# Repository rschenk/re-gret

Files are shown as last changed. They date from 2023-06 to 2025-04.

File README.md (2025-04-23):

# Re-gret Keyboard

The Re-gret is a 34 key remix of my [Egret](https://github.com/rschenk/egret) keyboard.

Featuring: 34 keys, Choc spacing, Choc v1 hot swappable, Seeed Xiao MCU, wireless compatible, RGB undeglow when plugged in, and a silicone gasket sandwich stackup.

Compared to the original Egret, besides having two thumb buttons per side, the Re-gret has a more angle between the halves, and the ring and pinky fingers have more stagger and more splay. It also has a Xiao MCU which is cheaper and cuter than a Nice Nano. Certainly a more re-fined re-mix that I have no re-grets about making.

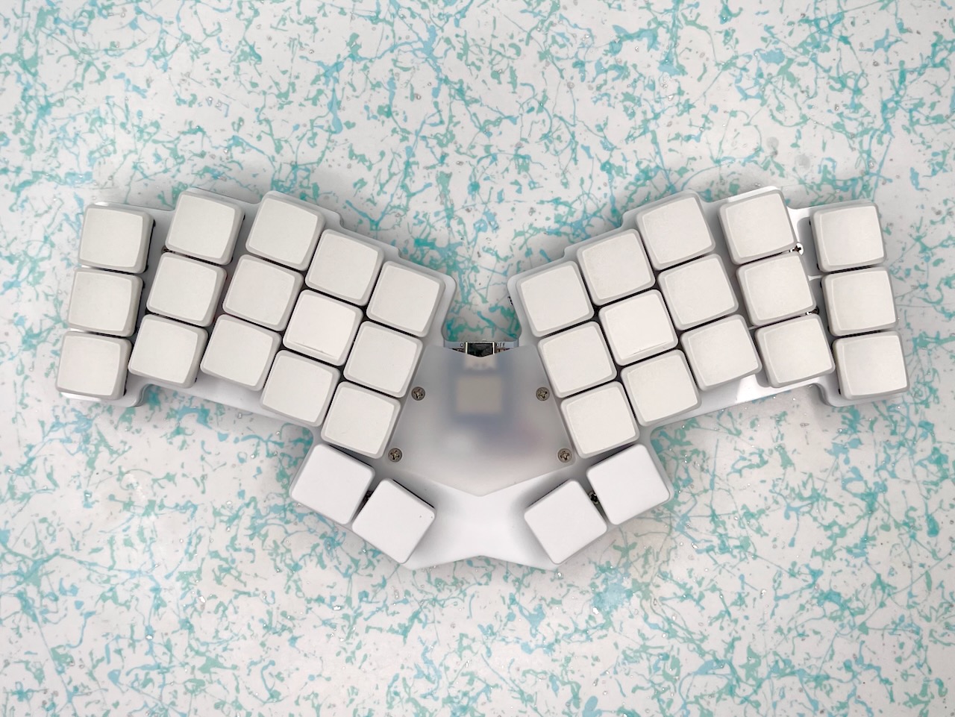
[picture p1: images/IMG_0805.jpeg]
Re-gret Bluetooth Mode


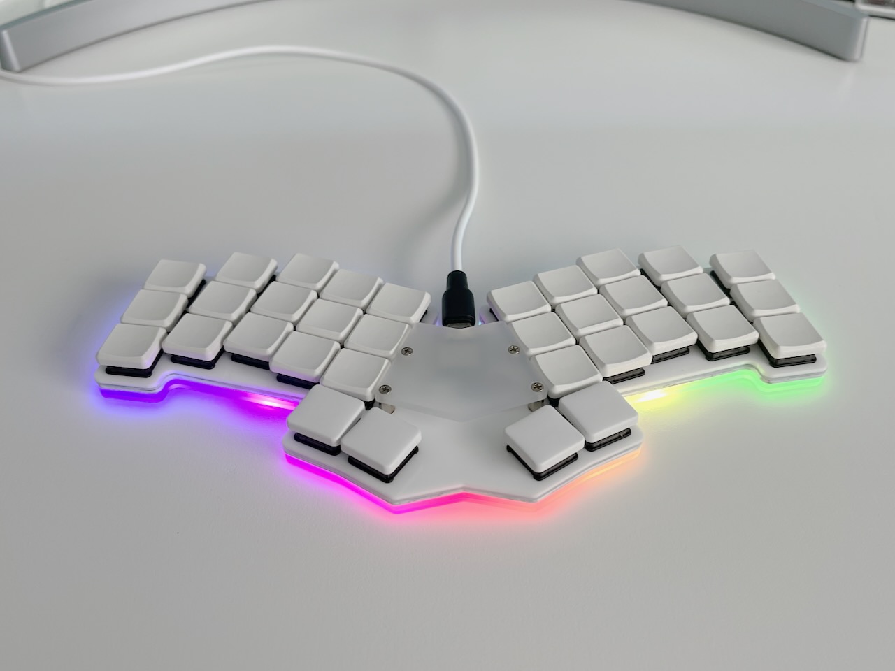
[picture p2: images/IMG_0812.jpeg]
Re-gret Underglow


## Build guide

Check the docs for a [PCB Build Guide](docs/pcb_build_guide.md) and [Case Build Guide](docs/case_build_guide.md).

## RGB Underglow

I powered the RGB underglow directly from the USB 5v, so it will automagically turn itself off when in wireless bluetooth mode. There's no need for ZMK's [External Power Control](https://zmk.dev/docs/behaviors/power#external-power-control) because you physically can't run the LEDs from battery power even if you wanted to. There's a [clever trick](https://hackaday.com/2017/01/20/cheating-at-5v-ws2812-control-to-use-a-3-3v-data-line/) using a diode that allows the 5v LEDs to be controlled by the Xiao's 3.3v logic.

## Firmware

### ZMK

I've published the firmware for Re-gret as a ZMK module: [rschenk/zmk-keyboard-re-gret](https://github.com/rschenk/zmk-keyboard-re-gret), which is (probably?) the preferred method for adding the keyboard in ZMK.

If you don't use modules, or prefer the old school way, then copy the contents of `firmware/zmk/config/boards/shields/regret/` into `[your-zmk-config]/config/boards/shields/regret/`

Be advised that right now the underglow only works on the XIAO nRF52840 board, and does not work on the XIAO RP2040 (although it [might in the future](https://github.com/zmkfirmware/zmk/issues/1085)). The original XIAO SAMD21 should work but I haven't tested it.

| Board | Chip | USB Wired | Bluetooth Wireless | RGB Underglow | Comments |
| --- | --- | --- | --- | --- | --- |
| XIAO | SAMD21 | :white_check_mark: | :x: | :x: | Should work but untested |
| XIAO BLE | nRF52840 | :white_check_mark: | :white_check_mark: | :white_check_mark: | |
| XIAO RP2040 | RP2040 | :white_check_mark: | :x: | :x: for now | Underglow [maybe someday](https://github.com/zmkfirmware/zmk/issues/1085) |

### QMK

Copy the contents of `firmware/qmk/keyboards/re_gret` into `[your_qmk_firmware]/keyboards/re_gret`, since I have not put the Re-gret firmware into the official QMK repo.

Only the XIAO RP2040 is supported. The Adafruit QT Py RP2040 might possibly work but I don't think the reset button will function.

| Board | Chip | USB Wired | RGB Underglow | Comments |
| --- | --- | --- | --- | --- |
| XIAO RP2040 | RP2040 | :white_check_mark: | :white_check_mark: |  |

## Related

* I cribbed the Xiao footprint, pogo pin idea, and battery from the [revxlp](https://gitlab.com/lpgalaxy/revxlp)
* I based the QMK shift register matrix code on [Sadek's](https://github.com/sadekbaroudi/qmk_firmware)
* My original 36 key [Egret](https://github.com/rschenk/egret) was the starting point

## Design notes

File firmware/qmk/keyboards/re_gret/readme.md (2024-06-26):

# Re-gret

re_gret

A 34-key keyboard powered by a Seeed XIAO RP2040, with hot-swappable ChocV1 switches.

* Keyboard Maintainer: [Ryan Schenk](https://github.com/rschenk)
* Hardware Supported: Re-gret PCB with Seeed XIAO RP2040 controller
* Hardware Availability: Gerbers are available in the [Re-gret repo](https://github.com/rschenk/re-gret) and the controller is available from [Seeed Studio](https://www.seeedstudio.com/XIAO-RP2040-v1-0-p-5026.html)

Make example for this keyboard (after setting up your build environment):

    make re_gret:default

Flashing example for this keyboard:

    make re_gret:default:flash

See the [build environment setup](https://docs.qmk.fm/#/getting_started_build_tools) and the [make instructions](https://docs.qmk.fm/#/getting_started_make_guide) for more information. Brand new to QMK? Start with our [Complete Newbs Guide](https://docs.qmk.fm/#/newbs).

## Bootloader

Enter the bootloader in 3 ways:

* **Bootmagic reset**: Hold down the top-left key ("Q" on qwerty) and plug in the keyboard
* **Physical reset button**: Double click the reset button
* **Keycode in layout**: Press the key mapped to `QK_BOOT` if it is available

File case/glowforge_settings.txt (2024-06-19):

Laser cutting settings for Glowforge Pro

1/16" Acrylic:
Speed: 241
Power: Full

To engrave the footpad wells:
Speed: 544
Power: 60
LPI: 270

Silicone Gasket:
Speed: 204
Power: 75

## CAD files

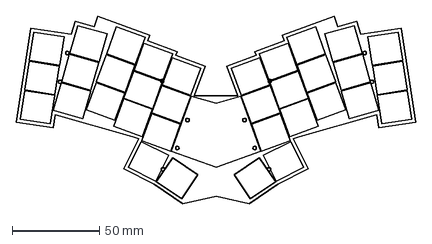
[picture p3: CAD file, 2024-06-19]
ergogen/output/outlines/comp.dxf
229.0 x 107.1 mm

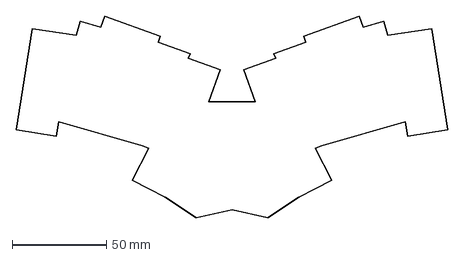
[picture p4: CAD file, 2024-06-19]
ergogen/output/outlines/board.dxf
229.0 x 107.1 mm

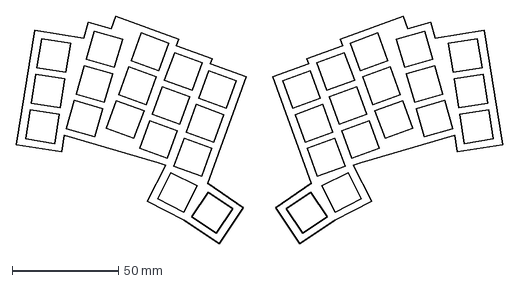
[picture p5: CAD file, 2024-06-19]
ergogen/output/outlines/top_plate.dxf
229.0 x 107.1 mm

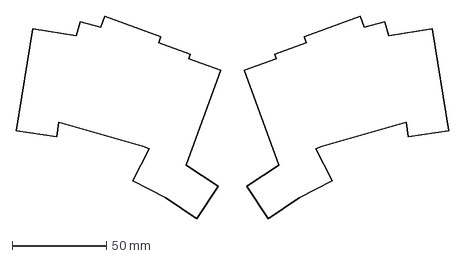
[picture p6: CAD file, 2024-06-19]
ergogen/output/outlines/raw.dxf
229.0 x 107.1 mm

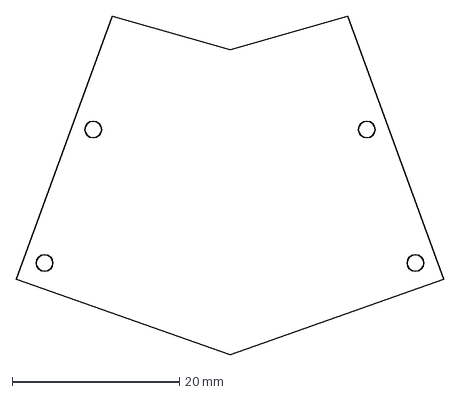
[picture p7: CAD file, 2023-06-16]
ergogen/output/outlines/mcu_cover.dxf
51.1 x 40.5 mm

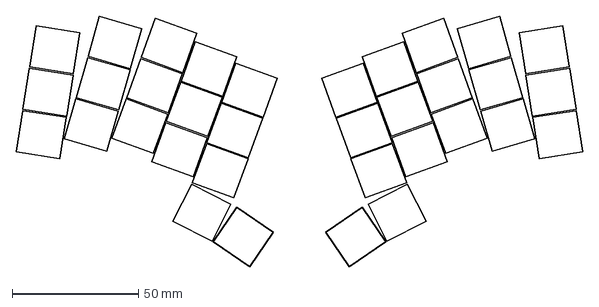
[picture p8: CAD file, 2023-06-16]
ergogen/output/outlines/keycaps.dxf
224.4 x 99.1 mm

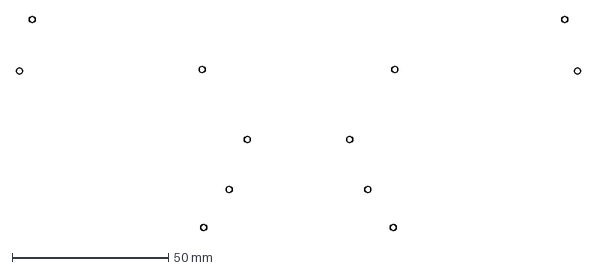
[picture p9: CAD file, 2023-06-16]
ergogen/output/outlines/all_mounting_holes.dxf
180.5 x 68.6 mm

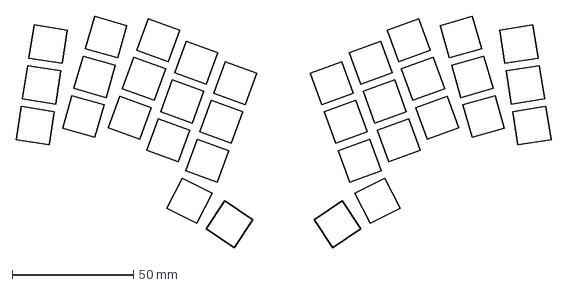
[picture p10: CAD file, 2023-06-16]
ergogen/output/outlines/switch_holes.dxf
220.4 x 95.3 mm

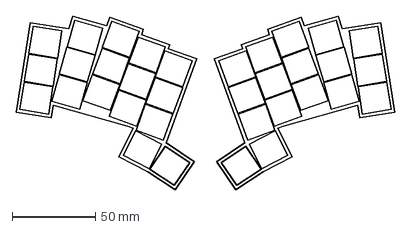
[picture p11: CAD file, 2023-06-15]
ergogen/output/outlines/keys.dxf
227.4 x 104.4 mm

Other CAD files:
case/dxf/Regret_Bottom_Plate_Outer.dxf
case/dxf/Regret_Bottom_Gasket.dxf
case/dxf/Regret_Bottom_Plate_Inner.dxf
case/dxf/Regret_Top_Plate.dxf
case/dxf/Regret_Top_Gasket.dxf
case/dxf/Regret_MCU_Cover.dxf

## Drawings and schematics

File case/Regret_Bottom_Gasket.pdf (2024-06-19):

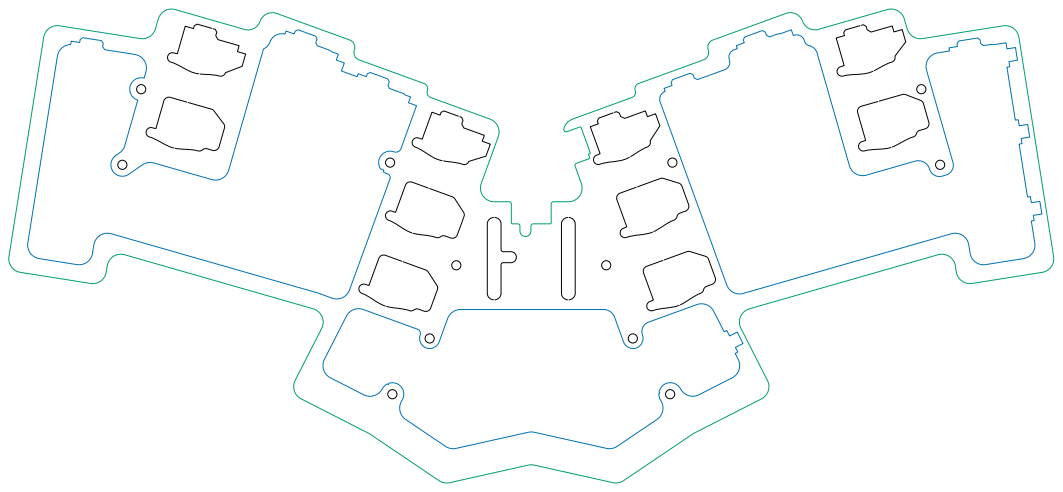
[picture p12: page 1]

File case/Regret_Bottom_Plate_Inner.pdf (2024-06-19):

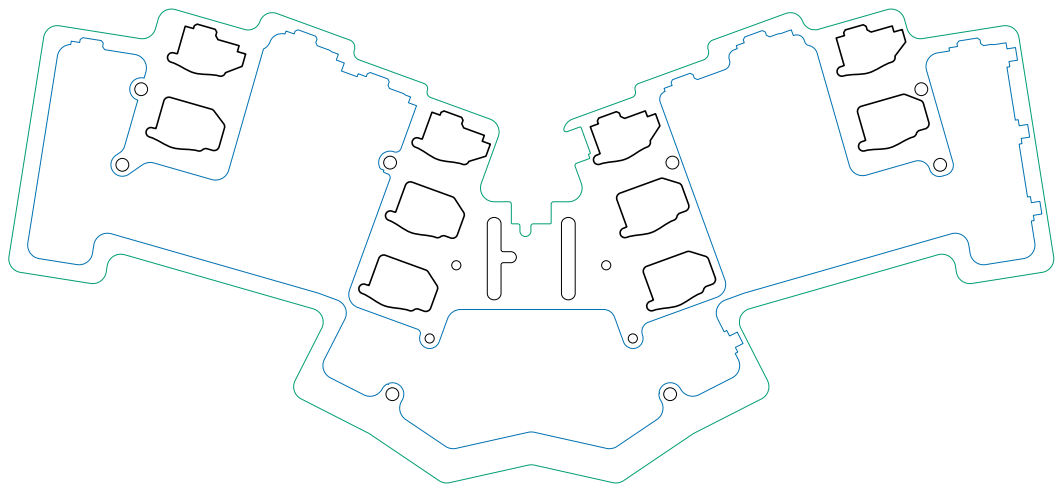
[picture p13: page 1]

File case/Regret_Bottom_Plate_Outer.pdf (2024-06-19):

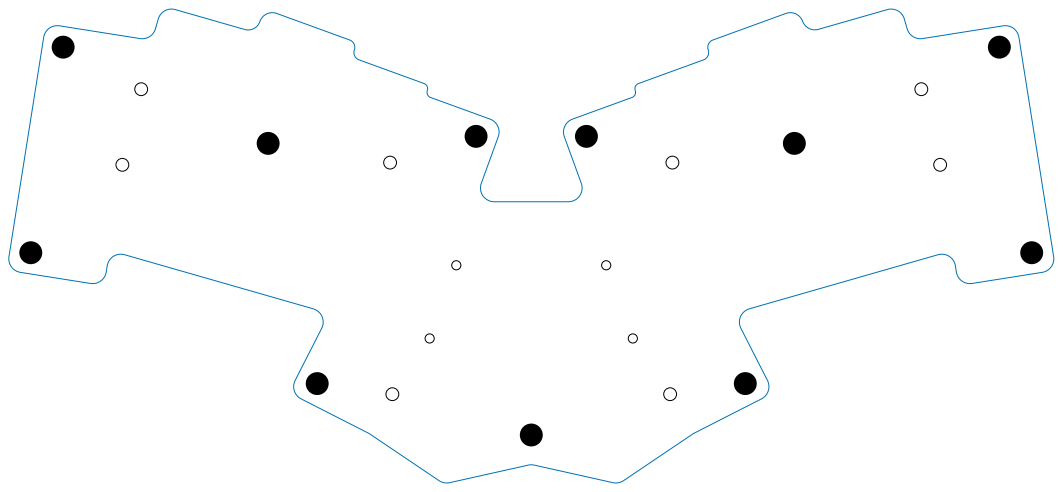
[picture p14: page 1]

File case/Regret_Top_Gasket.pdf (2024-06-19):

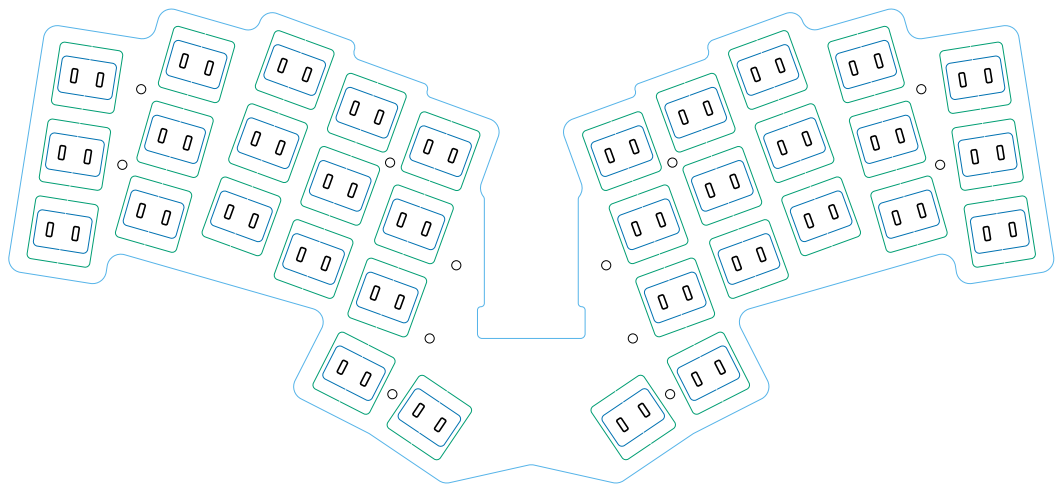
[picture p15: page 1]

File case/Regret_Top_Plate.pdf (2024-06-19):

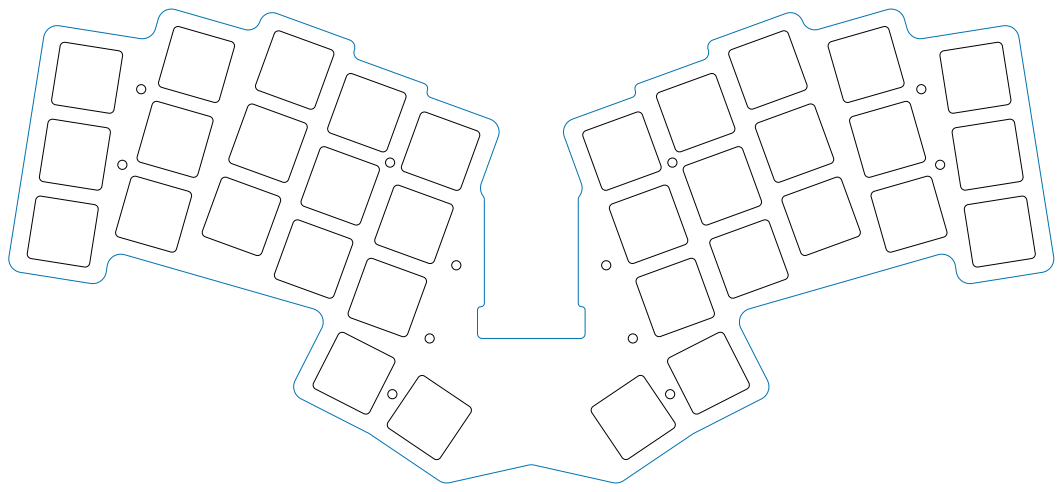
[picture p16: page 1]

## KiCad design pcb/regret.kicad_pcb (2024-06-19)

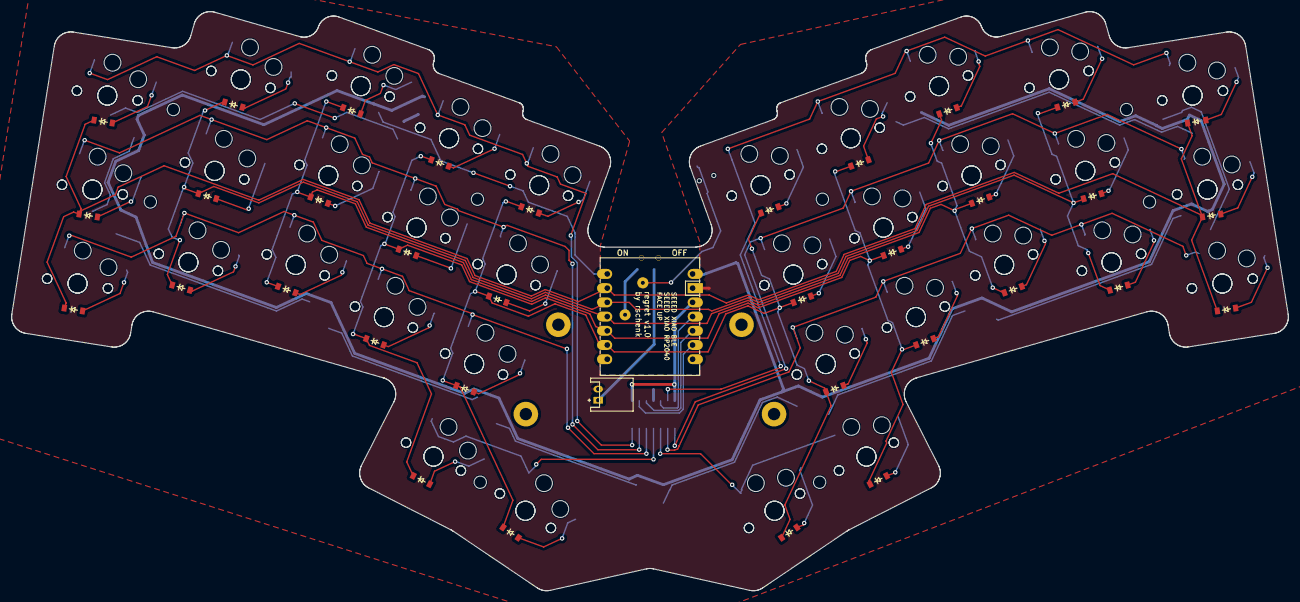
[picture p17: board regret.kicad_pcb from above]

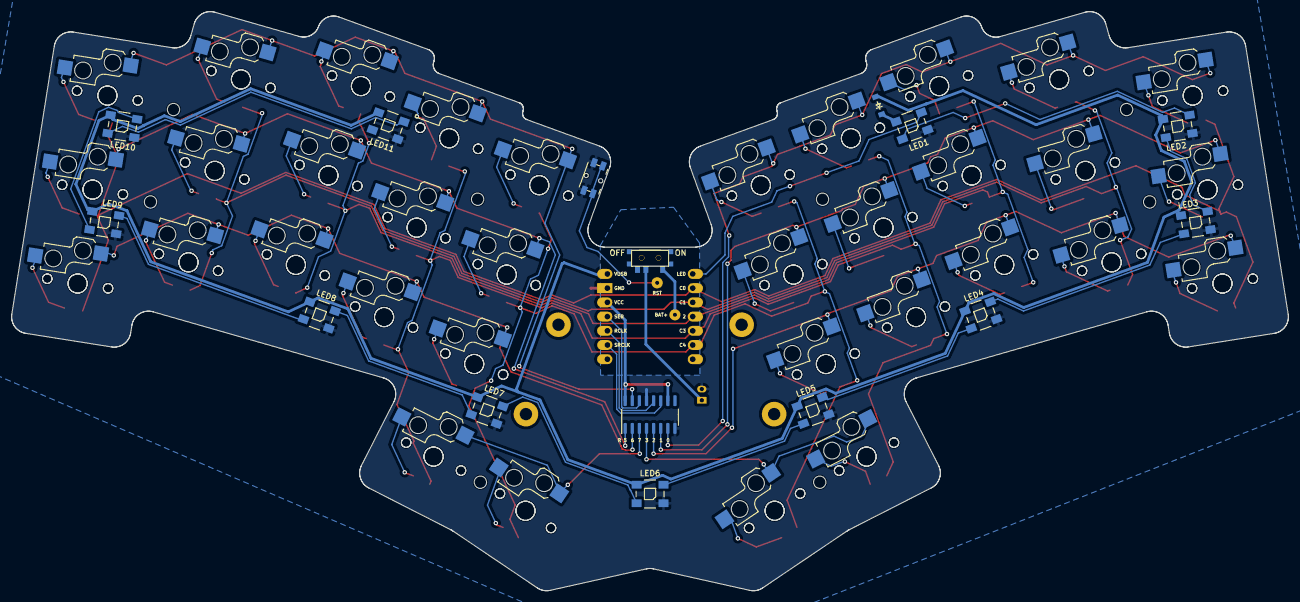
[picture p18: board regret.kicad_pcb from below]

Board: 2 copper layers, 228.1 x 103.5 mm, 131 parts (13 on the bottom side), 68 nets.

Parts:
19.051: 74HC595; SOIC-16_3.9x9.9mm_P1.27mm
B1: Panasonic_EVQPUL_EVQPUC
D1, D2, D3, D4, D5, D6, D7, D8, D9, D10, D11, D12, D13, D14, D15, D16, D17, D18, D19, D20, D21, D22, D23, D24, D25, D26, D27, D28, D29, D30, D31, D32, D33, D34, D35: ComboDiode
JST1: JST_PH_S2B-PH-K_02x2.00mm_Angled
LED1, LED2, LED3, LED4, LED5, LED6, LED7, LED8, LED9, LED10, LED11: VAL**; WS2812B
MCU1: xiao-ble
PAD1, PAD2, PAD3, PAD4: MountingHole_2.2mm_M2_Pad
PAD5, PAD6, PAD7, PAD8, PAD9, PAD10, PAD11, PAD12: MountingHole_2.2mm_M2
S1, S2, S3, S4, S5, S6, S7, S8, S9, S10, S11, S12, S13, S14, S15, S16, S17, S18, S19, S20, S21, S22, S23, S24, S25, S26, S27, S28, S29, S30, S31, S32, S33, S34: PG1350
SB1, SB2, SB3, SB4, SB5, SB6, SB7, SB8, SB9, SB10, SB11, SB12, SB13, SB14, SB15, SB16, SB17, SB18, SB19, SB20, SB21, SB22, SB23, SB24, SB25, SB26, SB27, SB28, SB29, SB30, SB31, SB32, SB33, SB34: ChocBonusGoodies
T1: SPDT_C128955

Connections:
BAT+: MCU1.19, T1.1
BAT_POS: JST1.1, T1.2
C0: D1.1, D2.1, D3.1, D16.1, D17.1, D18.1, MCU1.2
C1: D4.1, D5.1, D6.1, D19.1, D20.1, D21.1, MCU1.3
C2: D7.1, D8.1, D9.1, D22.1, D23.1, D24.1, MCU1.4
C3: D10.1, D11.1, D12.1, D25.1, D26.1, D27.1, D31.1, D33.1, MCU1.5
C4: D13.1, D14.1, D15.1, D28.1, D29.1, D30.1, D32.1, D34.1, MCU1.6
GND: 19.051.8, 19.051.13, B1.2, JST1.2, LED1.3, LED2.3, LED3.3, LED4.3, LED5.3, LED6.3, LED7.3, LED8.3, LED9.3, LED10.3, LED11.3, MCU1.13
L2: LED1.2, LED2.4
L3: LED2.2, LED3.4
L4: LED3.2, LED4.4
L5: LED4.2, LED5.4
L6: LED5.2, LED6.4
L7: LED6.2, LED7.4
L8: LED7.2, LED8.4
L9: LED8.2, LED9.4
L10: LED9.2, LED10.4
L11: LED10.2, LED11.4
LED: LED1.4, MCU1.1
R0: 19.051.7, S3.1, S6.1, S9.1, S12.1, S15.1
R1: 19.051.6, S2.1, S5.1, S8.1, S11.1, S14.1
R2: 19.051.5, S1.1, S4.1, S7.1, S10.1, S13.1
R3: 19.051.4, S31.1, S32.1
R4: 19.051.15, S18.1, S21.1, S24.1, S27.1, S30.1
R5: 19.051.1, S17.1, S20.1, S23.1, S26.1, S29.1
R6: 19.051.2, S16.1, S19.1, S22.1, S25.1, S28.1
R7: 19.051.3, S33.1, S34.1
RCLK: 19.051.12, MCU1.10
RST: B1.1, MCU1.17
SER: 19.051.14, MCU1.11
SRCLK: 19.051.11, MCU1.9
VCC: 19.051.10, 19.051.16, MCU1.12
VUSB: D35.2, LED2.1, LED3.1, LED4.1, LED5.1, LED6.1, LED7.1, LED8.1, LED9.1, LED10.1, LED11.1, MCU1.14
home_thumb: D31.2, S31.2
index_bottom: D10.2, S10.2
index_home: D11.2, S11.2
index_top: D12.2, S12.2
inner_bottom: D13.2, S13.2
inner_home: D14.2, S14.2
inner_top: D15.2, S15.2
led_1_v: D35.1, LED1.1
middle_bottom: D7.2, S7.2
middle_home: D8.2, S8.2
middle_top: D9.2, S9.2
mirror_home_thumb: D33.2, S33.2
mirror_index_bottom: D25.2, S25.2
mirror_index_home: D26.2, S26.2
mirror_index_top: D27.2, S27.2
mirror_inner_bottom: D28.2, S28.2
mirror_inner_home: D29.2, S29.2
mirror_inner_top: D30.2, S30.2
mirror_middle_bottom: D22.2, S22.2
mirror_middle_home: D23.2, S23.2
mirror_middle_top: D24.2, S24.2
mirror_pinky_bottom: D16.2, S16.2
mirror_pinky_home: D17.2, S17.2
mirror_pinky_top: D18.2, S18.2
mirror_reachy_thumb: D34.2, S34.2
mirror_ring_bottom: D19.2, S19.2
mirror_ring_home: D20.2, S20.2
mirror_ring_top: D21.2, S21.2
pinky_bottom: D1.2, S1.2
pinky_home: D2.2, S2.2
pinky_top: D3.2, S3.2
reachy_thumb: D32.2, S32.2
ring_bottom: D4.2, S4.2
ring_home: D5.2, S5.2
ring_top: D6.2, S6.2

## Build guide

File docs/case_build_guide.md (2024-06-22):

# Re-gret Case Build Guide

The Re-gret has a laser cut sandwich case of 1.5mm (1/16") acrylic and 0.7mm (1/32") silicone. The stackup looks like this:

```
switch plate
top gasket
PCB
bottom gasket
inner bottom plate
outer bottom plate
```

Also on the top gasket, there are a full set of my [Choc bumpers](https://github.com/rschenk/choc-bumpers) in the otherwise wasted material where the switch cutouts are.

## Parts to laser

| **Part**/File | Quantity | Comments |
| --- | --- | --- |
| [Top plate](../case/Regret_Top_Plate.pdf) | 1 | 1.5mm (1/16") acrylic. [Canal Plastics](https://www.canalplastic.com/collections/opaque-colored-acrylic-sheets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) |
| [Top gasket](../case/Regret_Top_Gasket.pdf) | 1 | 0.7mm (1/32") silicone. I like silicone placemats from [Amazon](https://www.amazon.com/gp/product/B088LKLSTG/). This from [McMaster](https://www.mcmaster.com/86465K21) would also probably work but I haven't tried it. |
| [Bottom gasket](../case/Regret_Bottom_Gasket.pdf) | 1 | 0.7mm (1/32") silicone. Ditto |
| [Inner bottom plate](../case/Regret_Bottom_Plate_Inner.pdf) | 1 | 1.5mm (1/16") acrylic. For best underglow action, you want to use frosted acrylic such as the Satin Ice (also the name of my RNB band) from [Canal  Plastics](https://www.canalplastic.com/collections/acrylic-sheets/products/0d010-df-frosted-satin-ice-acrylic-sheet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) |
| [Outer bottom plate](../case/Regret_Bottom_Plate_Outer.pdf) | 1 | 1.5mm (1/16") frosted acrylic. Ditto |
| [MCU cover](../case/Regret_MCU_Cover.pdf) | 1 | You could use the same frosted 1.5mm (1/16") acrylic as the bottom plates, however I prefer the look of this 3mm matte finish acrylic from [Makerstock](https://makerstock.com/products/acrylic-frosted-clear-frosted-acrylic) |

## Laser cutter settings

These are specific to the laser cutter that I use, a Glowforge Pro. If you have one then you can use these settings:

| Material | Speed | Power | LPI  |
| --- | ----- | ----- | ---- |
| 1/16" acrylic cutting | 241 | Full  | — |
| 1/16" acrylic raster engraving (footpad wells on the bottom) | 544 | 60 | 270  |
| 1/32" silicone cutting | 204 | 75 | — |

## Hardware

For the hardware you can either use wafer head screws, or countersunk flat head screws. You'll need a drill press and countersinking bit to utilize the latter, but that's how I do it.

| Part | Quantity | Comments |
| --- | --- | --- |
| 6mm M2 wafer head screws | 12 | **Option 1 of 2.** Use this option if you do not have a drill press. [Metric Screws US](https://www.metricscrews.us/index.php?main_page=index&cPath=155_156_162&zenid=ehth7nvdt09u23fh2sd1oqksk7) has singles |
| 6mm M2 flat head screws  | 12 | **Option 2 of 2.** Use this option if you have a drill press and countersink bit, to get the flattest possible design and because they're cheaper and easier to get. [McMaster](https://www.mcmaster.com/screws/system-of-measurement~metric/thread-size~m2/length~6-mm/flat-head-screws-4/material~stainless-steel/) |
| 8mm M2 wafer head screws | 4 | **Option 1 of 2.** Use this option if you do not have a drill press. [Metric Screws US](https://www.metricscrews.us/index.php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) has singles |
| 8mm M2 flat head screws  | 4 | **Option 2 of 2.** Use this option if you have a drill press and countersink bit, to get the flattest possible design and because they're cheaper and easier to get. [McMaster](https://www.mcmaster.com/screws/system-of-measurement~metric/thread-size~m2/length~8-mm/flat-head-screws-4/material~stainless-steel/) |
| 3mm M2 thraded inserts | 8 | PEM MSO4-M2-3 [McMaster](https://www.mcmaster.com/92985A818/) |
| 8mm M2 standoffs | 4 | [DigiKey](https://www.digikey.com/en/products/detail/würth-elektronik/970080244/9488540) or anywhere |
| Bottom grippy feet | 11 | Lots of options here. Personally I used some of this silicone from [McMaster](https://www.mcmaster.com/86465K34/) that I cut with a 1/8" hole punch. I raster-engraved little footwells in the bottom plate to receive them. EVA foam could also work [Amazon](https://www.amazon.com/dp/B07T5L7756/) |

## Case Assembly

If using counter sunk screws, then drill counter sinks on the mounting holes on the top plate, except for the four larger holes in the cente by the controller. Also counter sink the four center holes on the bottom plate, and the four holes on the MCU cover plate. To counter sink acrylic, I like the five-flute bits, use a low speed and light pressure and it will cut like butter. Skip this step if using wafer heads.

Press the eight threaded inserts into the bottom plate with the flange on the bottom side.

Install the switches and MCU. I like to do this now with the PCB sitting on the table, so that the force of setting the switche home is directed into the tabletop instaed of the solder holding the hotswap sockets on. Put the assembled PCB onto a table, put on the top gasket and top plate. You can slide a few screws into the holes to align all the layers. Then start installing switches. I like to install some on the corners and thumb cluster to help align everything, then do them all.

Install the MCU and battery. Please be careful with the battery polarity, it is marked on the PCB with a small  `+`, and is the so-called standard (according to Adafruit) of the positive (red) wire on the left. 

Place the inner bottom gasket (be careful, it only goes on one way) the inner bottom plate (ditto), and the outer bottom plate. Install the screws down from the top plate, then the ones for the MCU cover and standoffs. Install the cover and you're good to go.

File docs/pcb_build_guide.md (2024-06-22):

# Re-gret PCB Build Guide

## Parts for the circuit board

| Part | Quantity | Footprint | Value | Comments |
| --- | --- | --- | --- | --- |
| XIAO compatible controller | 1 | XIAO | XIAO BLE, XIAO, XIAO RP2040 | [Seeed Studio XIAO](https://www.seeedstudio.com/Seeed-XIAO-BLE-nRF52840-p-5201.html) or [Adafruit Qt Py](https://www.adafruit.com/category/595) |
| Shift register | 1 | SOIC-16 | SN74HC595 | SN74HC595DRG3 from TI ([DigiKey](https://www.digikey.com/en/products/detail/texas-instruments/SN74HC595DRG3/2600341)) |
| Socket headers | 2 | | Mill-Max 310-43-107-41-001000 | Mill-Max 310 series for wireless ([DigiKey](https://www.digikey.com/en/products/detail/mill-max-manufacturing-corp/310-43-107-41-001000/1212181)). You could also use low profile Mill-Max 315 series for a *wired-only version that also forgoes a reset button on the PCB.* ([DigiKey](https://www.digikey.com/en/products/detail/mill-max-manufacturing-corp/315-43-107-41-001000/4455221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)) |
| Socket pins | 14 | | Mill-Max 3320-0-00-15-00-00-03-0 | For socketing the controller. [DigiKey](https://www.digikey.com/en/products/detail/mill-max-manufacturing-corp/3320-0-00-15-00-00-03-0/4147392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) or use diode/resistor legs. Buy like 5 extras, you'll lose them. |
| Pogo pins | 2 | | Mill-Max 0906-2-15-20-75-14-11-0 | For reset and battery conection. Optional if you want a wired build with no reset button on the board. |
| LEDs | 11 | 5050 | WS2812B | aka Neopixels. There are several compatble chips, just makes sure you get the 5050 package. [DigiKey](https://www.digikey.com/en/products/detail/sparkfun-electronics/COM-16347/11630204) |
| Kailh Choc hot swap sockets | 34 | | CPG135001S30 | [DigiKey](https://www.digikey.com/en/products/detail/adafruit-industries-llc/5118/14671678) |
| Diodes | 35 | SOD123 | 1N4148W | If doing RGB undeglow you need 35, yes thirty five. If not doing RGB, you only need 34. [DigiKey](https://www.digikey.com/en/products/detail/smc-diode-solutions/1N4148W/6022450) |
| Reset button | 1 | | Panasonic EVQPUC02K | [DigiKey](https://www.digikey.com/en/products/detail/panasonic-electronic-components/EVQ-PUM02K/286341) |
| Slider switch | 1 | | PCM12 | Required for wireless, not needed for wired. MSK-12C02, or pretty sure CUS-12TB ([Digikey](https://www.digikey.com/en/products/detail/nidec-copal-electronics/CUS-12TB/1124222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)) will work but I haven't tried it. |
| JST PH2.0 battery jack (board side) | 1 | | JST S2B-PH-K-S | Nice for wireless, not needed for wired. You could also just solder the battery leads to the PCB.  [DigiKey](https://www.digikey.com/en/products/detail/jst-sales-america-inc/S2B-PH-K-S-LF-SN/926626) |
| JST PH2.0 plug (battery side) | 1 | | JST PHR-2 | A plug for the battery. Not needed for wired version or if soldering the battery to PCB [DigiKey](https://www.digikey.com/en/products/detail/jst-sales-america-inc/PHR-2/608607) |
| JST PH crimp connectors | 2 | | SPH-002T-P0.5L | Crimp connectors for the battery leads to go into the plug. For 28AWG wire. Ditto on wired version remarks. [DigiKey](https://www.digikey.com/en/products/detail/jst-sales-america-inc/SPH-002T-P0-5L/1300246) |
| Battery | 1 | 350820 | 40mAh | [Tiny Circuits](https://tinycircuits.com/collections/batteries/products/lithium-ion-polymer-battery-3-7v-40mah) |

## PCB Assembly

### Shift register

The first component to solder is the shift register, which has tiny pins and needs to be drag-soldered. Drag soldering is a technique where a tiny blob of solder is dragged back and forth across the pins instead of soldering each pin individually. If you've never done it before it sounds scary but it's actually very easy. The key is to use flux (I like [Chip Quik SMD291-5M](https://www.digikey.com/en/products/detail/chip-quik-inc/SMD291-5M/14636558)) which makes the whole thing kinda just work. [Here's a video](https://www.youtube.com/watch?v=wUyetZ5RtPs).

Tin one pad of the shift register footprint on the PCB. There's a dot on the shift register chip, and you'll notice the PCB silk screen has one long line and one short line. Line up the chip carefully with the dot towards the long line, then tack down the respective pin on the tinned pad. Make sure the chip is perfectly lined up with all the pads, then tack down the opposite corner. Now put flux along the row of pins, melt a tiny dab of solder on the tip of your iron, then drag it back and forth along the pins a few times. Have a look with a magnifying glass to make sure there are no bridges, then do the other side.

### RGB LEDs

First of all there is one diode near LED-1 that allows the 3.3v logic of the Xiao to control the 5v LEDs. You should solder that on now while there's nothing in the way. Then do the RGBs.

There is a great [video of how to solder these LEDs](https://twitter.com/GTIPS_SH/status/1204244088867807234?s=20) courtesy of Reviung. Tin one pad, tack the LED down, then do the other three pins with a dab of solder on the iron. Please pay attention to the silk screen on the board, there is a little notch cut out of the component, that will need to align with the corresponding notch on the silk screen. I like about 300ºC on the soldering iron. Much like the shift register, using flux is the difference between this being easy and annoying.

### Easy stuff

The reset button and power switch are easy and follow the same pattern: tin one pad, tack down the component, then solder on the rest of the pins. I do the same process with the hotswap sockets, tin one pad, place the socket, tack down that pad, then solder on the other one. 

Then do the controller sockets next. I put the controller in the sockets, then tape the whole thing down to the front of the board, flip it over and solder it. 

Solder the diodes onto the top next. Pay attention to the diode orientation, there's a line on the diode that matches up with the vertical line on the silkscreen.

The battery socket also goes in on the top side. You could also just solder the battery wires directly to the board. You will see that there is a `+` marked on the board, that's for the positive (red) lead on the battery.

### Pogo pins

I found these to be the most annoying part of the build. Take the controller out of the sockets. The two pogo pins are in between the sockets, under where the controller will go. The idea is to melt some solder in each hole, then hold the pin with tweezers over the hole while you reflow the solder in the hole and shove the pin in. I found this pretty fiddly and annoying.

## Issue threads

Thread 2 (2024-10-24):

Some Pics of case construction

SeebM, 2024-10-24:
Hi, I've got trouble imagining the bottom case construction with acrylic plates and silicon mats. Would you be willing to share some pictures of the assembly? It would help a lot in the build process!

rschenk, 2024-10-24:
Check the [egret repo](https://github.com/rschenk/egret), there are more pictures there and the case assembly is the same, cheers

SeebM, 2025-04-17:
Hi, I just wanted to share my finally finished re-gret build with you. Thanks for making your work publicly available. The bottom was designed by a friend of mine
https://www.printables.com/model/1176264-re-gret-keyboard-tray-mount-case

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

rschenk, 2025-04-17:
@SeebM Outstanding! It looks great, thanks for sharing!

Closed 2025-04-17.

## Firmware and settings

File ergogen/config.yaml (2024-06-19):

meta:
  engine: "4.0.0"
  version: 1
  author: rschenk

units:
  # Key spacing
  kx: cx            # Choc spacing
  ky: cy
  # Keycap size
  capw: 17.5        # MBK keycaps
  caph: 16.5
  # Mirroring
  center_spread: capw # Distance between inner top keys
  master_angle: 20  # Degrees that the halves are angled
  # Stagger
  ring_stagger: 8
  middle_stagger: 5.5
  index_stagger: -3.375
  inner_stagger: -2.375
  # Splay
  ring_splay: 7     # Between pinky and ring
  middle_splay: 4   # Between ring and middle
  # Thumb cluster
  thumb_shift_x: 0
  thumb_shift_y: -ky
  thumb_splay: 7

  # Outlines
  edge_border: 2    # Border around PCB, outside the keycaps' perimeter
  outer_kx: capw + 2edge_border
  outer_ky: caph + 2edge_border
  # bump the top-center of the mcu cover down to match the master angle
  cover_bump_top: -4
  cover_bump_bottom: -9 # ditto on bottom
  cover_hole_margin: 3  # Inset from the edge
  mounting_hole_r: 1
  standoff_clearance_hole_r: 2.75

  # Components
  xiao_w: 17.5
  xiao_h: 21
  bat_plug_w: 7.6
  bat_plug_h: 5.9

  # Laser cutting
  kerf: 0.006 * 25.4 # Inches

points:
  zones.matrix:
    # Fix placement on KiCAD sheet
    anchor:
      shift: [100, -100]
    mirror: &mirror
      ref: matrix_inner_top
      distance: center_spread
      shift: [capw/2, caph/2]
    rotate: -master_angle
    key:
      padding: ky
      spread: kx
      tags: [key]
    columns:
      pinky:
        key:
          splay: ring_splay + middle_splay
          column_net: C0
        rows:
          top.bind: [0, 5, 0, 0]
          home.bind: 0
          bottom.bind: 0
      ring:
        key:
          stagger: ring_stagger
          splay: -ring_splay
          origin: [-kx/2, -ky/2]
          column_net: C1
        rows:
          top.bind: 0
          home.bind: 0
          # Make the bottom of the plate cleaner
          bottom.bind: [0, 40, 0, 0]
      middle:
        key:
          stagger: middle_stagger
          splay: -middle_splay
          origin: [-kx/2, -ky/2]
          column_net: C2
      index:
        key:
          stagger: index_stagger
          column_net: C3
      inner:
        key:
          stagger: inner_stagger
          column_net: C4
    rows:
      bottom:
        row_net: R2
        mirror.row_net: R6
      home:
        row_net: R1
        mirror.row_net: R5
      top:
        row_net: R0
        mirror.row_net: R4

  zones.thumbs:
    mirror: *mirror
    anchor:
      ref: matrix_inner_bottom
      shift: [thumb_shift_x, thumb_shift_y]
    key:
      padding: ky
      spread: kx
      tags: [key]
    columns:
      home:
        key:
          splay: -thumb_splay
          origin: [-kx/2, kx/2]
          column_net: C3
      reachy:
        key:
          splay: -thumb_splay
          origin: [-kx/2, -kx/2]
          column_net: C4
    rows:
      thumb:
        row_net: R3
        mirror.row_net: R7

  zones.mcu_cover_mounting_hole_top:
    mirror: *mirror
    anchor:
      ref: matrix_inner_home
      shift: [capw/2 + cover_hole_margin, -caph/2 + cover_hole_margin]
    key.tags: [mcu_cover_mounting_hole]

  zones.mcu_cover_mounting_hole_bottom:
    $extends: points.zones.mcu_cover_mounting_hole_top
    anchor:
      ref: matrix_inner_bottom
      shift: [capw/2 + cover_hole_margin, -caph/2 + cover_hole_margin]

  zones.mounting_hole_ring_top:
    mirror: *mirror
    anchor:
      ref: matrix_ring_top
      shift: [-10.1, -ky/2]
    key.tags: [mounting_hole]

  zones.mounting_hole_ring_bottom:
    $extends: points.zones.mounting_hole_ring_top
    anchor:
      ref: matrix_ring_home
      shift: [-9.5, -ky/2]

  zones.mounting_hole_index_top:
    $extends: points.zones.mounting_hole_ring_top
    anchor:
      ref: matrix_index_top
      shift: [8.5, -ky/2]

  zones.mounting_hole_thumb:
    $extends: points.zones.mounting_hole_ring_top
    anchor:
      ref.aggregate.parts: [thumbs_home_thumb, thumbs_reachy_thumb]
      shift: [0, 0.3]

  # First LED is a "sacrificial" one to allow 3v3 logic to control a 5v LED.
  # See: https://hackaday.com/2017/01/20/cheating-at-5v-ws2812-control-to-use-a-3-3v-data-line/
  zones.led_1:
    mirror: *mirror
    anchor:
      ref: matrix_middle_top
      shift: [kx/2 - 2, -5]
    key:
      tags: [led]
      VCC: led_1_v
      din: led
      dout: L2
      mirror:
        VCC: VUSB
        din: L11
        dout: ''

  zones.led_2:
    $extends: points.zones.led_1
    anchor:
      ref: matrix_pinky_top
      shift: [3.5, -5]
    key:
      VCC: VUSB
      din: L2
      dout: L3
      mirror:
        din: L10
        dout: L11

  zones.led_3:
    $extends: points.zones.led_2
    anchor:
      ref: matrix_pinky_home
      shift: [3, -5.5]
    key:
      din: L3
      dout: L4
      mirror:
        din: L9
        dout: L10

  zones.led_4:
    $extends: points.zones.led_2
    anchor:
      ref: matrix_middle_bottom
      shift: [kx/2 - 2, -7]
    key:
      din: L4
      dout: L5
      mirror:
        din: L8
        dout: L9
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

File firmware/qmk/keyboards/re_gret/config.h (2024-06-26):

// Copyright 2024 Ryan Schenk (@rschenk)
// SPDX-License-Identifier: GPL-2.0-or-later

#pragma once

#define MATRIX_COLS 5
#define MATRIX_ROWS 8

#define SPI_SCK_PIN GP2
#define SPI_MOSI_PIN GP3
#define SPI_MISO_PIN NO_PIN

#define SHIFTREG_MATRIX_ROW_CS GP4
#define SHIFTREG_DIVISOR 8
#define SHIFTREG_COLS 5
#define SHIFTREG_ROWS 8

#define MATRIX_COL_PINS { GP27, GP28, GP29, GP6, GP7 }
// Row Number 0 1 2 3 4 5 6 7       
// SHR Pin Q: H G F E A B C D
#define SHIFTREG_ROW_PINS { 0x80, 0x40, 0x20, 0x10, 0x01, 0x02, 0x04, 0x08 }

#define WS2812_DI_PIN GP26
#define RGBLIGHT_LED_COUNT 11

#ifdef RGBLIGHT_ENABLE
  #define RGBLIGHT_EFFECT_RAINBOW_SWIRL   // enable rainbow swirl
  #define RGBLIGHT_SLEEP                  // turn off LEDs when host sleeps
  #define RGBLIGHT_LAYERS                 // per-layer LED effects
  #define RGBLIGHT_DEFAULT_MODE RGBLIGHT_MODE_RAINBOW_SWIRL
#endif

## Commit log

2023-06-16 footprint for sk6812-mini-e
2023-06-16 Embrace `mirror` for LED layout
    [all_mounting_holes.dxf, board.dxf, comp.dxf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]
2023-06-16 Hide mini-e LED ref
2023-06-16 Add sacrificial diode to LED1
    [regret.kicad_pcb]
2023-06-16 Change to mini-e leds for underglow
2024-10-24 SVG and DXF format case files
    [Regret_Bottom_Gasket.dxf, Regret_Bottom_Plate_Inner.dxf, Regret_Bottom_Plate_Outer.dxf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]
